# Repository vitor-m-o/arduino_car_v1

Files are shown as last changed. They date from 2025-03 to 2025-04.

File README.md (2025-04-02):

# arduino_car_v1

# DESCRIÇÃO DO PROJETO:
-  Projeto de carro de Arduino para facilitar o entendimento da programação para iniciantes.
-  Código desenvolvido para o teste de todas as funcionalidades do carro de Arduino, também para documentação das bibliotecas utilizadas para seu funcionamento, tanto como exemplos de boas maneiras e código.
-  Projeto da PCB do carro, no qual está sendo projetado para uma versão fisica aprimorada.
-  Não há versão digitalizada do antigo circuito.

# BIBLIOTECAS UTILIZADAS:
- Bibliotecas instaladas diretamente da IDE Arduino. Creditos aos seus devidos criadores.
- Ultrasonic
- U8glib
- SoftwareSerial

# NOTA:

- A conexão dos botões físicamente dos carros pode mudar por conta das condições utilizadas para variar entre os botões, porém ainda será revisado e aprimorado esta parte.

# PINAGEM:

# CARRO AMARELO:

# PINOS MOTORES:

- Ponte H N1 (MOVIMENTO ANTI-HORARIO ESQUERDA) -> 4
- Ponte H N2 (MOVIMENTO HORARIO ESQUERDA) -> 5
- Ponte H N3 (MOVIMENTO ANTI-HORARIO DIREITA) -> 11
- Ponte H N4 (MOVIMENTO HORARIO DIREITA) -> 6

# PINOS SENSORES REFLEXÃO:

- Pino sensor reflexão um -> A1
- Pino sensor reflexão dois -> A2
- Pino sensor reflexão tres -> A6
- Pino sensor reflexão quatro -> A7

# PINOS SENSORES ULTRASSONICOS:

- Pino sensor TRIG ultrassonico um -> 2
- Pino sensor ECHO ultrassonico um -> 3 
  
- Pino sensor TRIG ultrassonico dois -> 2
- Pino sensor ECHO ultrassonico dois -> 7
  
- Pino sensor TRIG ultrassonico tres -> 2
- Pino sensor ECHO ultrassonico tres -> 10

# TELA OLED:

- Pino SDA e SCL

# PINOS EXTRAS:

- Pino Divisão de tensão botões -> A0
- RX do bluetooth -> 0
- TX do bluetooth -> 1

# CARRO MARROM:

# PINOS MOTORES:

- Ponte H N1 (MOVIMENTO ANTI-HORARIO ESQUERDA) -> 4
- Ponte H N2 (MOVIMENTO HORARIO ESQUERDA) -> 5
- Ponte H N3 (MOVIMENTO ANTI-HORARIO DIREITA) -> 11
- Ponte H N4 (MOVIMENTO HORARIO DIREITA) -> 6

# PINOS SENSORES REFLEXÂO:

- Pino sensor reflexão um -> A1
- Pino sensor reflexão dois -> A2
- Pino sensor reflexão tres -> A6
- Pino sensor reflexão quatro -> A7

# PINOS SDA SCL:

- Tela OLED
- 3 Sensores Infravermelhos

# PINOS EXTRAS:

- Pino Divisão de tensão botões -> A0
- RX do bluetooth -> 0
- TX do bluetooth -> 1

# FUNÇÔES DO CÓDIGO:

- Ainda por comentar.

# Linguagem utilizada:


# Autor:

[<br><sub>Vítor Maziero Oliveira</sub>](https://github.com/vitor-m-o)

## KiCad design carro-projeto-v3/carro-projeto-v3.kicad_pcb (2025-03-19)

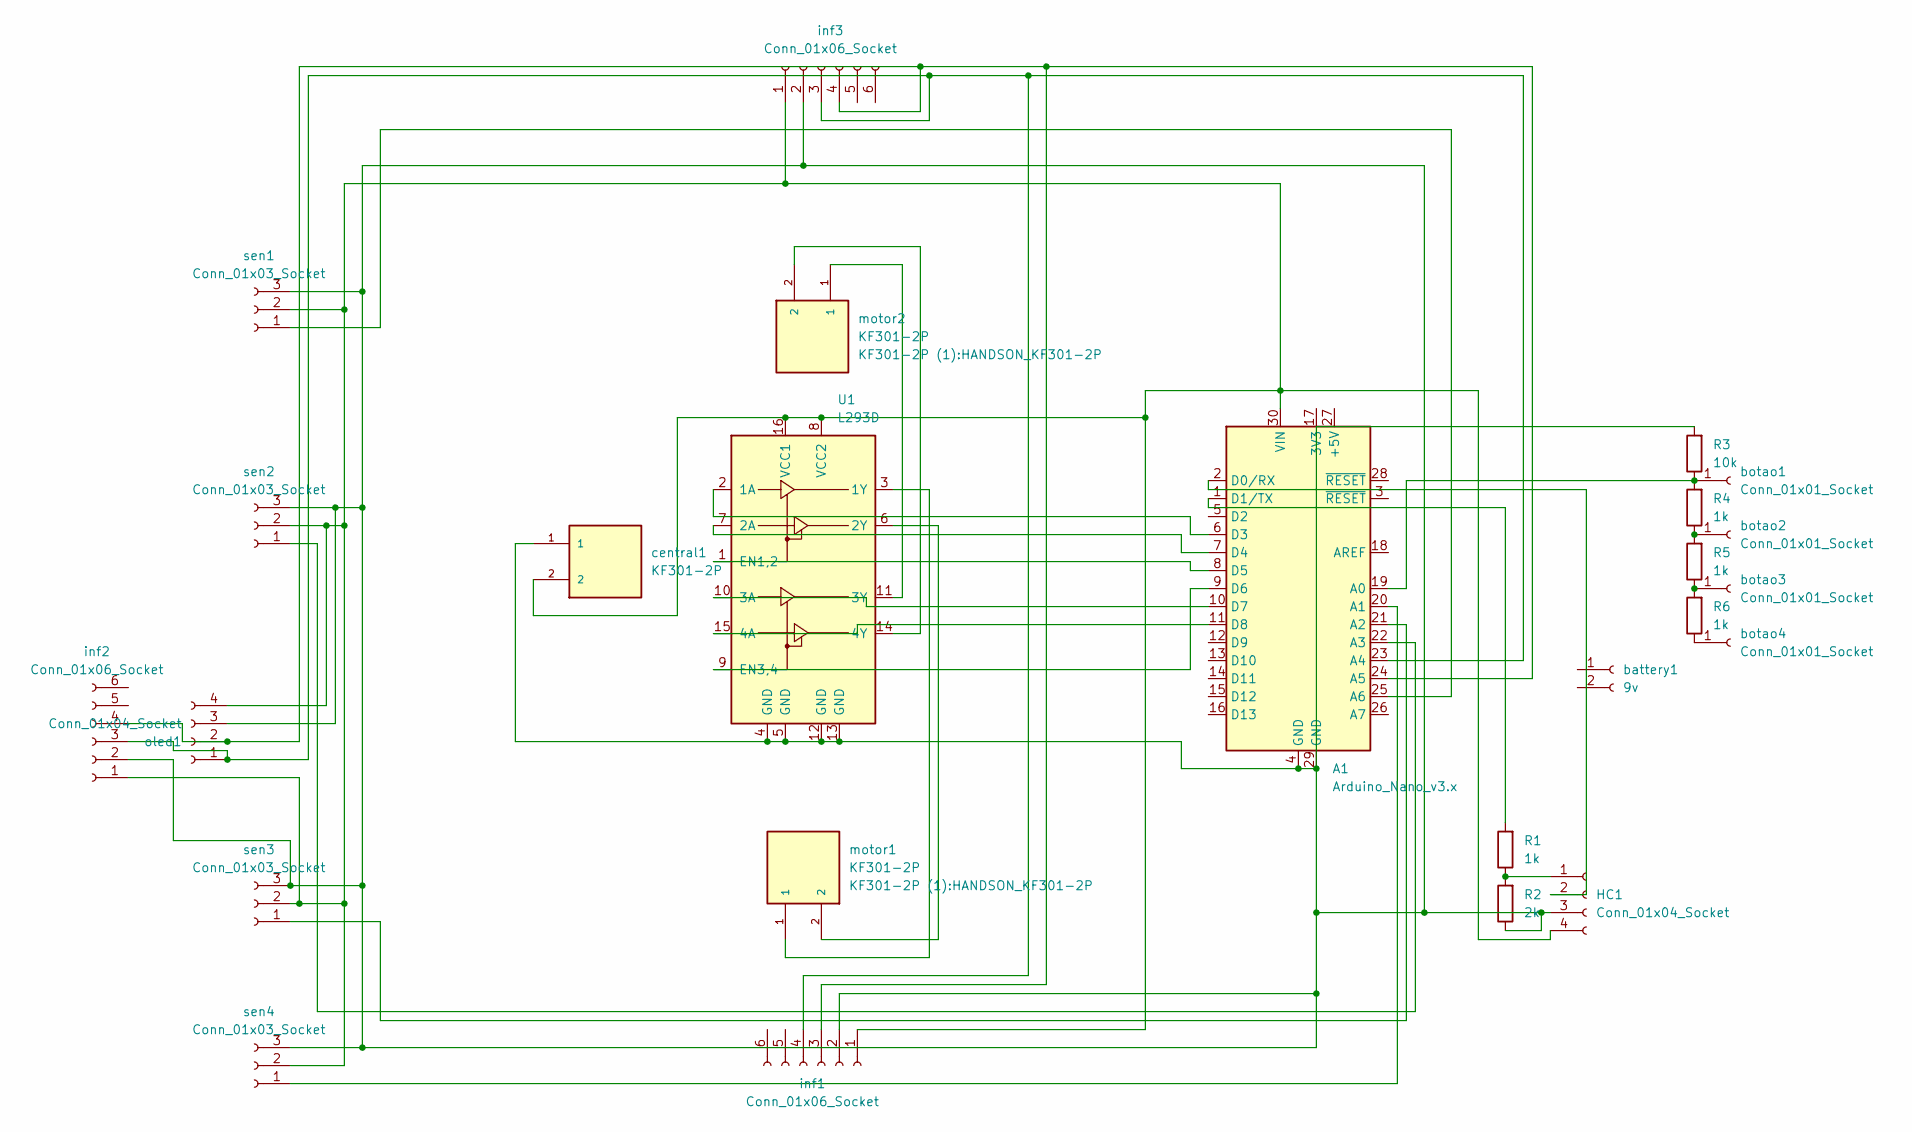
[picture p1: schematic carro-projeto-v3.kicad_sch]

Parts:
A1: Arduino_Nano_v3.x; Arduino_Nano
HC1: Conn_01x04_Socket; PinHeader_1x04_P2.54mm_Vertical
R1: 1k; R_Axial_DIN0204_L3.6mm_D1.6mm_P7.62mm_Horizontal
R2: 2k; R_Axial_DIN0204_L3.6mm_D1.6mm_P7.62mm_Horizontal
R3: 10k; R_Axial_DIN0207_L6.3mm_D2.5mm_P2.54mm_Vertical
R4, R5, R6: 1k; R_Axial_DIN0207_L6.3mm_D2.5mm_P2.54mm_Vertical
U1: L293D; DIP-16_W7.62mm
battery1: 9v
botao1, botao2, botao3, botao4: Conn_01x01_Socket; PinHeader_1x01_P2.54mm_Vertical
central1: KF301-2P; HANDSON_KF301-2P; PARTREV NA
inf1, inf2, inf3: Conn_01x06_Socket; PinHeader_1x06_P2.54mm_Vertical
motor1, motor2: KF301-2P; HANDSON_KF301-2P; PARTREV NA
oled1: Conn_01x04_Socket; PinHeader_1x04_P2.54mm_Vertical
sen1, sen2, sen3, sen4: Conn_01x03_Socket; PinHeader_1x03_P2.54mm_Vertical

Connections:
unnamed: A1.19 (A0), R3.1, R4.2, botao1.1
unnamed: A1.20 (A1), sen4.1
unnamed: A1.21 (A2), sen3.1
unnamed: A1.22 (A3), sen2.1
unnamed: A1.23 (A4), inf1.4, inf2.3, inf3.3, oled1.1
unnamed: A1.24 (A5), inf1.3, inf2.4, inf3.4, oled1.2
unnamed: A1.25 (A6), sen1.1
unnamed: A1.2 (D0/RX), HC1.2
unnamed: A1.1 (D1/TX), R1.2
unnamed: A1.6 (D3), U1.2 (1A)
unnamed: A1.7 (D4), U1.7 (2A)
unnamed: A1.8 (D5), U1.1 (EN1,2)
unnamed: A1.9 (D6), U1.9 (EN3,4)
unnamed: A1.10 (D7), U1.10 (3A)
unnamed: A1.11 (D8), U1.15 (4A)
unnamed: A1.30 (VIN), HC1.4, U1.8 (VCC2), U1.16 (VCC1), central1.2, inf1.1, inf2.1, inf3.1, oled1.4, sen1.2, sen2.2, sen3.2, sen4.2
unnamed: HC1.1, R1.1, R2.2
unnamed: A1.4 (GND), A1.29 (GND), HC1.3, R2.1, R3.2, U1.4 (GND), U1.5 (GND), U1.12 (GND), U1.13 (GND), central1.1, inf1.2, inf2.2, inf3.2, oled1.3, sen1.3, sen2.3, sen3.3, sen4.3
unnamed: U1.3 (1Y), motor1.1
unnamed: U1.6 (2Y), motor1.2
unnamed: U1.11 (3Y), motor2.1
unnamed: U1.14 (4Y), motor2.2
unnamed: R4.1, R5.2, botao2.1
unnamed: R5.1, R6.2, botao3.1
unnamed: R6.1, botao4.1

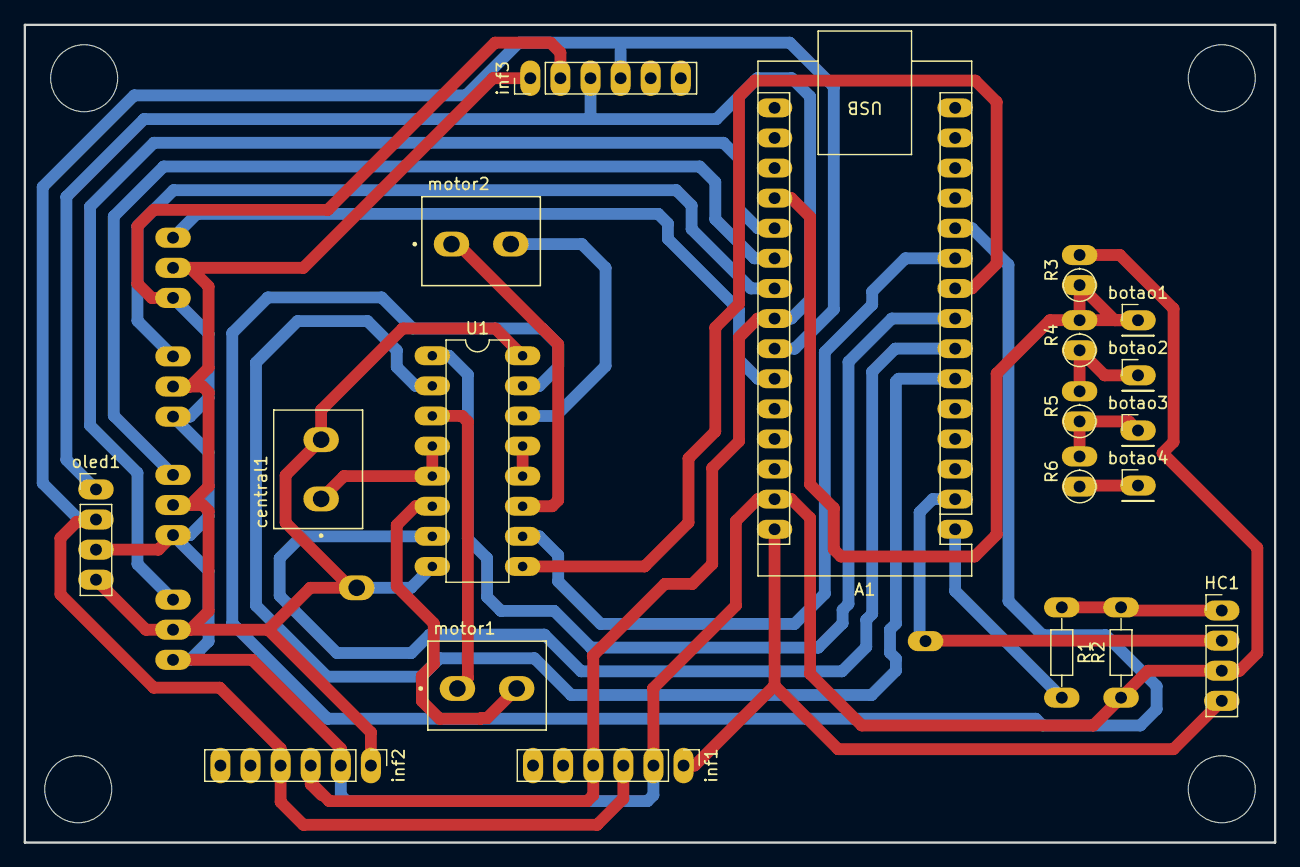
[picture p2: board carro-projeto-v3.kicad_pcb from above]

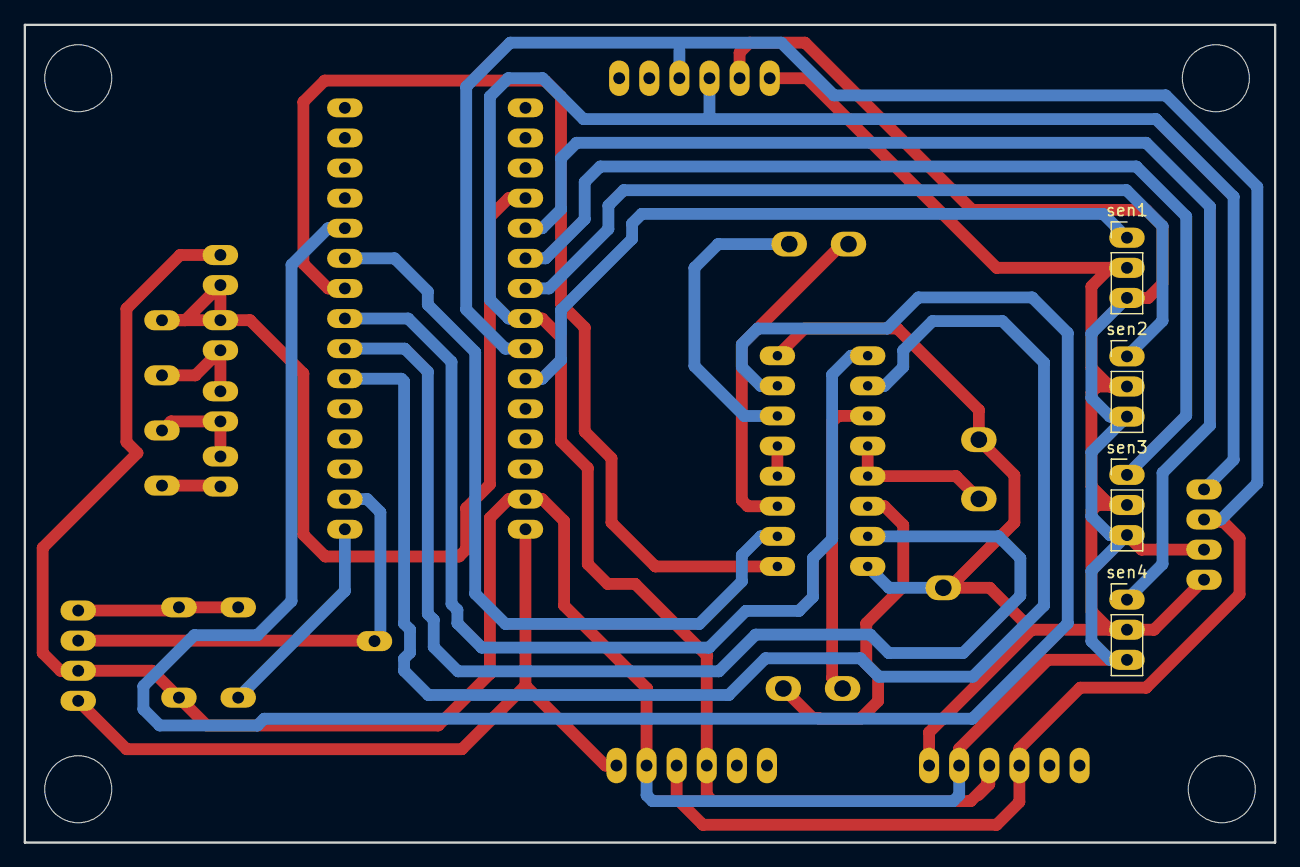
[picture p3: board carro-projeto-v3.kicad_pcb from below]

Board: 2 copper layers, 105.5 x 69.0 mm, 24 parts (4 on the bottom side), 25 nets.

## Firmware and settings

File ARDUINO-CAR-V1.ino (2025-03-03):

//=====VITOR-M-O=====//
//=====TINF1M=====//
//=====PROGRAMA-EM-ARDUINO-PARA-CONTROLAR-CARRO-ARDUINO-COM-BLUETOOTH-E-MOSTRAR-INFORMACOES-NA-TELA-OLED=====//

//=====CHAMAR-BIBLIOTECA-UTILIZADA-PARA-USAR-ULTRASSONICO=====//
#include <Ultrasonic.h>

//=====CHAMAR-BIBLIOTECA-UTILIZADA-PARA-USAR-TELA-OLED=====//
#include "U8glib.h"

//=====DEFINIR-NOME-PARA-CLASSE-DE-FUNCOES-DA-TELA-OLED=====//
U8GLIB_SSD1306_128X64 oled(U8G_I2C_OPT_NO_ACK);

//=====DEFINIR-VARIAVEL-UTILIZADA-PARA-ESCREVER-NA-TELA-OLED=====//
char stringVar[10]; 

//=====DEFINIR-VARIAVEL-DE-CONTROLE-PARA-VALOR-LIDO-POR-BLUETOOTH=====//
char var = '\0';

//=====DEFINIR-VARIAVEL-UTILIZADA-PARA-DETERMINAR-SE-A-TELA-OLED-RESETARA=====//
bool displayReboot;

//=====CHAMAR-BIBLIOTECA-PARA-USAR-BLUETOOTH=====//
#include <SoftwareSerial.h>

//=====DEFINIR-NOME-PARA-CLASSE-DE-FUNCOES-DO-BLUETOOTH=====//
SoftwareSerial hc06(12,13);

//=====DEFINIR-VARIAVEL-PARA-LER-VALOR-RECEBIDO-PELO-BLUETOOTH=====//
char readBlue;

//=====DEFINIR-PINOS-UTILIZADOS-PARA-ULTRASSONICO=====//
#define pino_trigger1 2
#define pino_echo1 3

#define pino_trigger2 2
#define pino_echo2 7

#define pino_trigger3 2
#define pino_echo3 10

//=====DEFINIR-NOME-PARA-CLASSE-DE-FUNCOES-DO-ULTRASSONICO=====//
Ultrasonic ultrassonic1(pino_trigger1, pino_echo1);  
Ultrasonic ultrassonic2(pino_trigger2, pino_echo2);  
Ultrasonic ultrassonic3(pino_trigger3, pino_echo3);  

//=====DEFINIR-VARIAVEL-PARA-LER-DISTANCIA-DO-ULTRASSONICO=====//
unsigned int distance1;
unsigned int distance2;
unsigned int distance3;

//=====PORTAS-PARA-PONTE-H=====//
  #define trasEsq 4    //N1
  #define frenteEsq 5 //N2
  #define trasDir 11   //N3
  #define frentedir 6  //N4

//=====PORTAS-SENSORES-DE-REFLEXAO-BINARIOS=====//
  #define sen_1_pin A1
  #define sen_2_pin A2
  #define sen_3_pin A6
  #define sen_4_pin A7
  
  int sen_1;
  int sen_2;
  int sen_3;
  int sen_4;

  int ult_1;
  int ult_2;
  int ult_3;

//=====VARIAVEL-PARA-CONTROLAR-VELOCIDADE=====//
  int VEL = 150;
//=====VARIAVEL-PARA-CONTROLAR-VELOCIDADE-EM-CURVAS=====//
  int curvaVel = 150;
//=====VELOCIDADE-PARA-CONTROLVAR-VELOCIDADE-DA-RODA-DE-SUPORTE=====//
  int suporteVel = 150;

  int velocidade = 0;
  
  int velocidadeNeg = 0;

//=====VARIAVEL-PARA-CONTROLAR-MOVIMENTO-DO-CARRO=====//
  int carState;

  int buttonState;
  int buttonAction;
  #define button A0

//=====VARIAVEIS-UTILIZADAS-PARA-CONTROLAR-O-CURSOR-DA-TELA=====//
  int y = 30;
  int x = 2;

//=====VARIAVEIS-UTILIZADAS-PARA-MEDIR-O-TEMPO=====//
  int tempoAtual;
  int tempoAnterior;
  int tempoAnterior1;
  int tempoAnterior2;

//=====PROTOCOLO-INICIAL=====//
void setup() {
  //=====INICIALIZAR-O-MILLIS-CONTADOR-DE-MILISEGUNDOS=====//
  millis();
  
  //=====INICIALIZAR-SERIAL=====//
  Serial.begin(9600);
  
  //=====INICIARLIZAR-COMUNICACAO-SERIAL=====//
  hc06.begin(9600);

  //=====COMUNICAR-NO-SERIAL-MONITOR-FUNCIONAMENTO=====//
  Serial.println("Pronto para funcionamento!");

  //=====DEFINIR-PORTAS-E-SUAS-FUNCOES-PONTE-H=====//
  pinMode(trasEsq, OUTPUT);
  pinMode(frenteEsq, OUTPUT);
  pinMode(trasDir, OUTPUT);
  pinMode(frentedir, OUTPUT);
  
  //=====DEFINIR-PORTAS-E-SUAS-FUNCOES-SENSORES-REFLEXAO=====//
  pinMode(sen_1_pin, INPUT);
  pinMode(sen_2_pin, INPUT);
  pinMode(sen_3_pin, INPUT);
  pinMode(sen_4_pin, INPUT);

  //=====DESENHAR-TELA-INICIAL-COM-LOGO-DO-IFSUL=====//

  //=====PARTE-INICIALIZADORA-PARA-DESENHAR-NA-TELA=====//
  oled.firstPage();
  do {
  //=====PARTE-INICIALIZADORA-PARA-DESENHAR-NA-TELA=====//

    //=====DEFINIR-FONTE-UTILIZADA=====//
    oled.setFont(u8g_font_10x20);
    
    //=====DEFINIR-AS-COORDENADAS-E-O-TEXTO-PARA-MOSTRAR-NA-TELA-OLED=====//
    oled.drawStr(15, 35, "IF");

    oled.setFont(u8g_font_5x7);
    
    oled.drawStr(40, 25, "Instituto Federal");

    oled.drawStr(40, 35, "SUL-RIO-GRANDENSE");
    
    oled.drawStr(40, 45, "Campus Camaqua");
    
  //=====PARTE-FINALIZADORA-PARA-DESENHAR-NA-TELA=====//
  } while (oled.nextPage());
  //=====PARTE-FINALIZADORA-PARA-DESENHAR-NA-TELA=====//

  //=====ESPERAR-3-SEGUNDOS=====//
  delay(3000);

  //=====DESENHAR-UMA-TELA-COM-A-INSTRUÇÃO-DA-UTILIZAÇÃO-DOS-BOTOÕES-DO-CARRO-ATÉ-QUE-O-USUÁRIO-APERTE-ALGUM-BOTAO=====//
  while (buttonState < 400)
  {
    buttonState = analogRead(button);

    oled.firstPage();
    do {
      oled.setFont(u8g_font_5x7);

      oled.drawStr(25, 10, "BOTOES DO PAINEL");
      
      oled.drawStr(5, 25, "o");

      oled.drawStr(10, 25, "SELECIONAR");

      
      oled.drawStr(5, 45, "o");

      oled.drawStr(10, 45, "VOLTAR");


      oled.drawStr(90, 25, "o");

      oled.drawStr(95, 25, "CIMA");


      oled.drawStr(90, 45, "o");

      oled.drawStr(95, 45, "BAIXO");


      oled.drawStr(10, 60, "APERTE QUALQUER BOTAO");

    } while (oled.nextPage());

  }

}

void loop() 
{
  //=====UTILIZAR-FUNCAO-PARA-DESENHAR-NA-TELA-DA-TELA-OLED=====//
  draw();

  //=====LER-O-VALOR-DO-PINO-DO-BOTAO=====//
  buttonState = analogRead(button);

  //=====IMPRIMIR-NO-SERIAL-MONITOR-O-VALOR-RECEBIDO-DO-BOTAO-E-O-SEU-ESTADO=====//
  Serial.println(buttonState);
  Serial.println(buttonAction);

  //=====VERIFICAÇÃO-DA-TENSAO-DO-PINO-PARA-PODER-DETERMINAR-QUAL-BOTAO-FOI-CLICADO=====//
  if (buttonState < 600)
  {
    buttonAction = 0;
  }
  else if (buttonState < 800)
  {
    buttonAction = 1;
  }
  else if (buttonState < 900)
  {
    buttonAction = 2;
  }
  else if (buttonState < 1000)
  {
    buttonAction = 3;
  }
  else
  {
    buttonAction = 4;
  }

  //=====DETERMINAR-QUAL-FUNÇÃO-O-BOTÃO-REALIZARÁ-DE-ACORDO-COM-O-BOTAO-PRESSIONADO=====//

  //=====SE-O-BOTAO-2-FOR-PRESSIONADO=====//
  if (buttonAction == 2)
  {
    //=====ESPERAR-200-MILISEGUNDOS=====//
    delay(200);

    //=====SE-A-COORDENADA-DO-Y-FOR-30=====//
    if (y == 30)
    {
      //=====SE-A-COORDENADA-DO-X-FOR-2=====//
      if (x == 2)
      {
        //=====DEFINIR-NOVAS-CORDENADAS=====//
        y = 55;
        x = 60;
      }
      //=====SENÃO=====//
      else
      {
        y = 55;
        x = 2;
      }
    }
    else
    {
      y = y - 25;
    }
  }
  else if (buttonAction == 3)
  {
    delay(200);

    if (y == 55)
    {
      if (x == 2)
      {
        y = 30;
        x = 60;
      }
      else
      {
        y = 30;
        x = 2;
      }
    }
    else
    {
      y = y + 25;
    }
  }

}

void draw()
{
  if (buttonAction == 1)
  {
    if ((y == 30) && (x == 2))
    {
      delay(300);
      buttonState = 0;
      oled.firstPage();
      
      do {

        oled.setFont(u8g_font_5x8);
        
        oled.drawStr(30, 10, "MODO BLUETOOTH");
        
        oled.drawStr(0, 30, "CONECTE-SE PARA CONTROLAR");

        oled.drawStr(10, 50, "APERTE QUALQUER BOTAO");
        oled.drawStr(40, 60, "PARA SAIR");

      } while (oled.nextPage());
      while (buttonState < 600)
      {
        buttonState = analogRead(button);
        
          //=====VERIFICAR-SE-O-BLUETOOTH-ESTA-DISPONIVEL=====//
          if (hc06.available()) 
          {
            //=====LER-VALOR-RECEBIDO-PELO-BLUETOOTH=====//
            readBlue = hc06.read(); 
            //=====DESCARTAR-VALORES-NULOS-E-DESNECESSARIOS-COM-FUNCAO-DE-PULAR-LINHA=====//
            if (readBlue != '\r' && readBlue != '\n')
            {
              //=====IMPRIMIR-VALOR-RECEBIDO-PELO-BLUETOOTH=====//
              //Serial.print("Recebido: ");
              //Serial.println(readBlue);    
            
              //=====COMPARAR-SE-O-VALOR-E-IGUAL-AO-CARACTERE-F=====//
              if (readBlue == 'F')
              {
                //=====MOVER-O-CARRO-PARA-FRENTE=====//
                moverCarro(0, VEL, 0, VEL);
              } 
              //=====SENAO-COMPARAR-SE-O-VALOR-E-IGUAL-AO-CARACTERE-R=====//
              else if (readBlue == 'R')
              {
                //=====MOVER-O-CARRO-PARA-DIREITA=====//
                moverCarro(0, 0, 0, curvaVel);
              }
              //=====SENAO-COMPARAR-SE-O-VALOR-E-IGUAL-AO-CARACTERE-L=====//
              else if (readBlue == 'L')
              {
                //=====MOVER-O-CARRO-PARA-ESQUERDA=====//
                moverCarro(0, curvaVel, 0, 0);
              }
              //=====SENAO-COMPARAR-SE-O-VALOR-E-IGUAL-AO-CARACTERE-B=====//
              else if (readBlue == 'B')
              {
                //=====MOVER-O-CARRO-PARA-TRAS=====//
                moverCarro(140, 0, 140, 0);
              }
              //=====SENAO-COMPARAR-SE-O-VALOR-E-IGUAL-AO-CARACTERE-S=====//
              else if (readBlue == 'S')
              {
                //=====PARAR-O-CARRO=====//
                moverCarro(0, 0, 0, 0);
              }
              //=====SENAO-COMPARAR-SE-O-VALOR-E-IGUAL-AO-CARACTERE-Q=====//
              else if (readBlue == 'Q')
              {
                //=====MOVER-O-CARRO-PARA-FRENTE-E-ESQUERDA=====//
                moverCarro(0, VEL, 0, suporteVel);
              }
              //=====SENAO-COMPARAR-SE-O-VALOR-E-IGUAL-AO-CARACTERE-Z=====//
              else if (readBlue == 'Z')
              {
                //=====MOVER-O-CARRO-PARA-TRAS-E-ESQUERDA=====//
                moverCarro(VEL, 0, suporteVel, 0);
              }
              //=====SENAO-COMPARAR-SE-O-VALOR-E-IGUAL-AO-CARACTERE-E=====//
              else if (readBlue == 'E')
              {
                //=====MOVER-O-CARRO-PARA-FRENTE-E-DIREITA=====//
                moverCarro(0, suporteVel, 0, VEL);
              }
              //=====SENAO-COMPARAR-SE-O-VALOR-E-IGUAL-AO-CARACTERE-C=====//
              else if (readBlue == 'C')
              {
                //=====MOVER-O-CARRO-PARA-TRAS-E-DIREITA=====//
                moverCarro(suporteVel, 0, VEL, 0);
              }
              //=====SENAO-COMPARAR-SE-O-VALOR-E-IGUAL-AO-CARACTERE-Z=====//
              else if (readBlue == 'X')
              {
                //=====GIRAR-O-CARRO-PARA-ESQUERDA=====//
                moverCarro(0, VEL, 140, 0);
              }
              //=====SENAO-COMPARAR-SE-O-VALOR-E-IGUAL-AO-CARACTERE-Y=====//
              else if (readBlue == 'Y')
              {
                //=====GIRAR-O-CARRO-PARA-DIREITA=====//
                moverCarro(VEL, 0, 0, VEL);
              }
            }
          }
      }

      moverCarro(0, 0, 0, 0);
      delay(300);
    }
    else if ((y == 55) && (x == 2))
    {
      delay(300);
      buttonState = 0;

      oled.firstPage();
      do {

        oled.setFont(u8g_font_5x8);
        
        oled.drawStr(35, 10, "MODO AUTONOMO");
        
        oled.drawStr(30, 25, "CARRO AUTONOMO" );
        oled.drawStr(22, 35, "SEGUIDOR DE LINHA" );

        oled.drawStr(10, 50, "APERTE QUALQUER BOTAO");
        oled.drawStr(40, 60, "PARA SAIR");

      } while (oled.nextPage());

      while (buttonState < 600)
      {
        buttonState = analogRead(button);

        //=====LER-VALORES-DOS-SENSORES-DE-REFLEXAO=====//
        sen_1 = analogRead(sen_1_pin);
        sen_2 = analogRead(sen_2_pin);
        sen_3 = analogRead(sen_3_pin);
        sen_4 = analogRead(sen_4_pin);

        //distance1 = ultrassonic1.read();
        //Serial.println(distance1);

        //=====IDENTIFICAR-VALOR-DO-SENSOR=====//
        
        //=====SE-O-SENSOR-1-E-4-NAO-RECEBEREM-REFLEXAO-OU-O-SENSOR-1-E-3-OU-O-SENSOR-4-E-2=====//
        //=====DEFINIR-VARIAVEL-PARA-CONTROLAR-MOVIMENTO-DO-CARRO-COMO-0=====//
        if (sen_1 < 10 && sen_4 < 10) carState = 0;
        else if (sen_1 < 10 && sen_3 < 10) carState = 0;
        else if (sen_4 < 10 && sen_2 < 10) carState = 0;
        else if (sen_4 < 10 && sen_3 < 10) carState = 4;
        //else if (sen_1 < 10 && sen_2 < 10) carState = 1;
        //else if (sen_2 < 10 && sen_3 < 10) carState = 5;
        //=====SE-A-CONDICAO-ANTERIOR-NAO-FOR-VERDADEIRA-VERIFIQUE-SE-O-SENSOR-1-NAO=RECEBER-REFLEXAO=====//
        //=====DEFINIR-VARIAVEL-PARA-CONTROLAR-MOVIMENTO-DO-CARRO-COMO-1=====//
        else if (sen_1 < 10) carState = 1;
        //=====SE-AS-CONDICOES-ANTERIORES-NAO-FOREM-VERDADEIRAS-VERIFIQUE-SE-O-SENSOR-2-NAO=RECEBER-REFLEXAO=====//
        //=====DEFINIR-VARIAVEL-PARA-CONTROLAR-MOVIMENTO-DO-CARRO-COMO-2=====//
        else  if (sen_2 < 10) carState = 2;
        //=====SE-AS-CONDICOES-ANTERIORES-NAO-FOREM-VERDADEIRAS-VERIFIQUE-SE-O-SENSOR-3-NAO=RECEBER-REFLEXAO=====//
        //=====DEFINIR-VARIAVEL-PARA-CONTROLAR-MOVIMENTO-DO-CARRO-COMO-3=====//
        else if (sen_3 < 10) carState = 3;
        //=====SE-AS-CONDICOES-ANTERIORES-NAO-FOREM-VERDADEIRAS-VERIFIQUE-SE-O-SENSOR-4-NAO=RECEBER-REFLEXAO=====//
        //=====DEFINIR-VARIAVEL-PARA-CONTROLAR-MOVIMENTO-DO-CARRO-COMO-4=====//
        else if (sen_4 < 10) carState = 4;
        //=====SE-AS-CONDICOES-ANTERIORES-NAO-FOREM-VERDADEIRAS=====//
        else carState = 0;
        
        //=====VERIFICACAO-DE-CASOS-ESPECIFICOS-DA-VARIAVEL-QUE-DEFINE-O-MOVIMENTO-DO-CARRO=====//
        switch (carState) 
        {
          //=====SE-A-VARIAVEL-FOR-1=====//
          case 1: 
            //=====MOVER-O-MOTOR-ESQUERDO-PARA-TRAS=====//
            moverCarro(0, 0, VEL, 0);
            //=====SAIR-DESTA-CONDICAO=====//
            break;
          //=====SE-A-VARIAVEL-FOR-2=====//
          case 2:
            //=====MOVER-O-MOTOR-DIREITO-PARA-FRENTE=====//
            moverCarro(0, suporteVel, 0, 0);
            //=====SAIR-DESTA-CONDICAO=====//
            break;
          //=====SE-A-VARIAVEL-FOR-3=====//
          case 3:
            //=====MOVER-O-MOTOR-ESQUERDO-PARA-FRENTE=====//
            moverCarro(0, 0, 0, 150);
            //=====SAIR-DESTA-CONDICAO=====//
            break;
          //=====SE-A-VARIAVEL-FOR-4=====//
          case 4:
            //=====MOVER-O-MOTOR-DIREITO-PARA-TRAS=====//
            moverCarro(VEL, 0, 0, 0);
            //=====SAIR-DESTA-CONDICAO=====//
            break;
          //=====SE-A-VARIAVEL-FOR-0=====//
          case 0:
            //=====MOVER-AMBOS-OS-MOTORES-PARA-FRENTE=====//
            moverCarro(0, suporteVel, 0, suporteVel);
            //=====SAIR-DESTA-CONDICAO=====//
            break;
          case 5:
            moverCarro(suporteVel, 0, suporteVel, 0);
            break;
        }
      }

      moverCarro(0, 0, 0, 0);
      delay(300);
    }
    else if ((y == 30) && (x == 60))
    {

      delay(300);
      buttonState = 0;

      oled.firstPage();
      do {

        oled.setFont(u8g_font_5x8);
        
        oled.drawStr(30, 10, "MODO LABIRINTO");
        
        oled.drawStr(30, 25, "CARRO AUTONOMO" );
        oled.drawStr(18, 35, "PERCORRER LABIRINTO" );

        oled.drawStr(10, 50, "APERTE QUALQUER BOTAO");
        oled.drawStr(40, 60, "PARA SAIR");

      } while (oled.nextPage());

      tempoAtual = millis();
      tempoAnterior = tempoAtual;
      while (buttonState < 600)
      {
        buttonState = analogRead(button);

        //=====ult_1 -> ultrassonico esquerda=====//
        //=====ult_2 -> ultrassonico central=====//
        //=====ult_3 -> ultrassonico direita=====//

        tempoAtual = millis();

        if (tempoAtual - tempoAnterior1 > 50)
        {
          ult_1 = ultrassonic1.read();
          ult_2 = ultrassonic2.read();
          ult_3 = ultrassonic3.read();

          tempoAnterior1 = tempoAtual;
        }

        /*
        if (ult_2 > 10)
        {
        moverCarro(0, 120, 0, 120);
        }
        else
        {
          if (ult_1 > ult_3)
          {
            while (ult_2 < 20)
            {
              ult_2 = ultrassonic2.read();
              moverCarro(0,120,0,0);
            }
          }
          else if (ult_3 > ult_1)
          {
            while(ult_2 < 20)
            {
              ult_2 = ultrassonic2.read();
              moverCarro(0,0,0,120);
            }
          }
        }
        */

        int velocidade = 60 + ult_2 * 1.2;

        if (ult_2 > 5)
        {
          moverCarro(0,velocidade,0,velocidade);
          Serial.println("CENTRO!!!");
        }
        //   /*
        else
        {
          moverCarro(0,0,0,0);
          while (tempoAtual - tempoAnterior2 < 300)
          {
            tempoAtual = millis();
            if (ult_1 > ult_3)
            {
              tempoAtual = millis();
              tempoAnterior = tempoAtual;
              while(tempoAtual - tempoAnterior < 170)
              {
                tempoAtual = millis();
                moverCarro(0,130,130,0);
                Serial.println("ESQUERDA!!!");
              }
              moverCarro(0,0,0,0);
              tempoAnterior = tempoAtual;
              while(tempoAtual - tempoAnterior < 300)
              {
                tempoAtual = millis();
                ult_2 = ultrassonic2.read();
                Serial.println("LENDO!!!");
              }
              tempoAnterior = tempoAtual;
            }
            else
            {
              tempoAtual = millis();
              tempoAnterior = tempoAtual;
              while(tempoAtual - tempoAnterior < 170)
              {
                tempoAtual = millis();
                moverCarro(130,0,0,130);
                Serial.println("DIREITA!!!");
              }
              moverCarro(0,0,0,0);
              tempoAnterior = tempoAtual;
              while(tempoAtual - tempoAnterior < 300)
              {
                tempoAtual = millis();
                ult_2 = ultrassonic2.read();
                Serial.println("LENDO!!!");
              }
              tempoAnterior = tempoAtual;
            }

          }
          tempoAnterior2 = tempoAtual;
        }
          

        
      }
      moverCarro(0,0,0,0);

      delay(300);
    }
    else if ((y == 55) && (x == 60))
    {
      
      delay(300);
      buttonAction = 0;

      x = 25;
      y = 30;

      while (buttonAction != 4)
      {
        buttonState = analogRead(button);

        if (buttonState < 600)
        {
          buttonAction = 0;
        }
        else if (buttonState < 800)
        {
          buttonAction = 1;
        }
        else if (buttonState < 900)
        {
          buttonAction = 2;
        }
        else if (buttonState < 1000)
        {
          buttonAction = 3;
        }
        else
        {
          buttonAction = 4;
        }

        if (buttonAction == 2)
        {
          delay(200);

          if (y == 30)
          {
            y = 60;
          }
          else
          {
            y = y - 15;
          }
        }
        else if (buttonAction == 3)
        {
          delay(200);

          if (y == 60)
          {
            y = 30;
          }
          else
          {
            y = y + 15;
          }
        }

        if (buttonAction == 1)
        {
          if (y == 30)
          {
            delay(300);
            buttonState = 0;

            while (buttonState < 600)
            {
              buttonState = analogRead(button);

              sen_1 = analogRead(sen_1_pin);
              sen_2 = analogRead(sen_2_pin);
              sen_3 = analogRead(sen_3_pin);
              sen_4 = analogRead(sen_4_pin);

              oled.firstPage();
              do {

                oled.setFont(u8g_font_5x8);
                
                oled.drawStr(20, 10, "TESTANDO SENSORES");
                oled.drawStr(35, 20, "DE REFLEXAO" );

                if (sen_1 < 10)
                {
                  oled.drawStr(25, 35, "0" );
                }
                else
                {
                  oled.drawStr(25, 35, "1" );
                }

                if (sen_2 < 10)
                {
                  oled.drawStr(50, 35, "0" );
                }
                else
                {
                  oled.drawStr(50, 35, "1" );
                }

                if (sen_3 < 10)
                {
                  oled.drawStr(70, 35, "0" );
                }
                else
                {
                  oled.drawStr(70, 35, "1" );
                }

                if (sen_4 < 10)
                {
                  oled.drawStr(95, 35, "0" );
                }
                else
                {
                  oled.drawStr(95, 35, "1" );
                }

                oled.drawStr(10, 50, "APERTE QUALQUER BOTAO");
                oled.drawStr(40, 60, "PARA SAIR");

              } while (oled.nextPage());

            }

            buttonAction = 0;
            delay(300);
            
          }
          else if (y == 45)
          {
            delay(300);

            buttonState = 0;

            while (buttonState < 600)
            {
              buttonState = analogRead(button);

              ult_1 = ultrassonic1.read();
              ult_2 = ultrassonic2.read();
              ult_3 = ultrassonic3.read();

              Serial.println(ult_1);
              Serial.println(ult_2);
              Serial.println(ult_3);

              char ult1s[10]; 
              sprintf(ult1s, "%d", ult_1); 

              char ult2s[10]; 
              sprintf(ult2s, "%d", ult_2); 

              char ult3s[10]; 
              sprintf(ult3s, "%d", ult_3); 

              oled.firstPage();
              do {

                oled.setFont(u8g_font_5x8);
                
                oled.drawStr(20, 10, "TESTANDO SENSORES");
                oled.drawStr(35, 20, "ULTRASSONICOS" );

                oled.drawStr(40, 35, ult1s );
                oled.drawStr(60, 35, ult2s );
                oled.drawStr(80, 35, ult3s );
                
                oled.drawStr(10, 50, "APERTE QUALQUER BOTAO");
                oled.drawStr(40, 60, "PARA SAIR");

              } while (oled.nextPage());

            }

            buttonAction = 0;
            delay(300);
          }

          else
          {
            buttonAction = 0;
            buttonState = 0;
            velocidade = 0;

            delay(300);

            while (buttonState < 400)
            {

              buttonState = analogRead(button);

              oled.firstPage();
              do {
                oled.setFont(u8g_font_5x7);
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

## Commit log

2025-03-03 KiCad PCB project for a new physical version
    [carro-projeto-v3.kicad_pcb, carro-projeto-v3.kicad_sch]
2025-03-03 Definir linguagem como Arduino
2025-03-19 update kicad project
    [carro-projeto-v3.kicad_pcb, carro-projeto-v3.kicad_sch]
